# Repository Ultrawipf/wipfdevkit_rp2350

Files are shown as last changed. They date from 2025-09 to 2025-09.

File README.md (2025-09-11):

## DM 14 Wipf

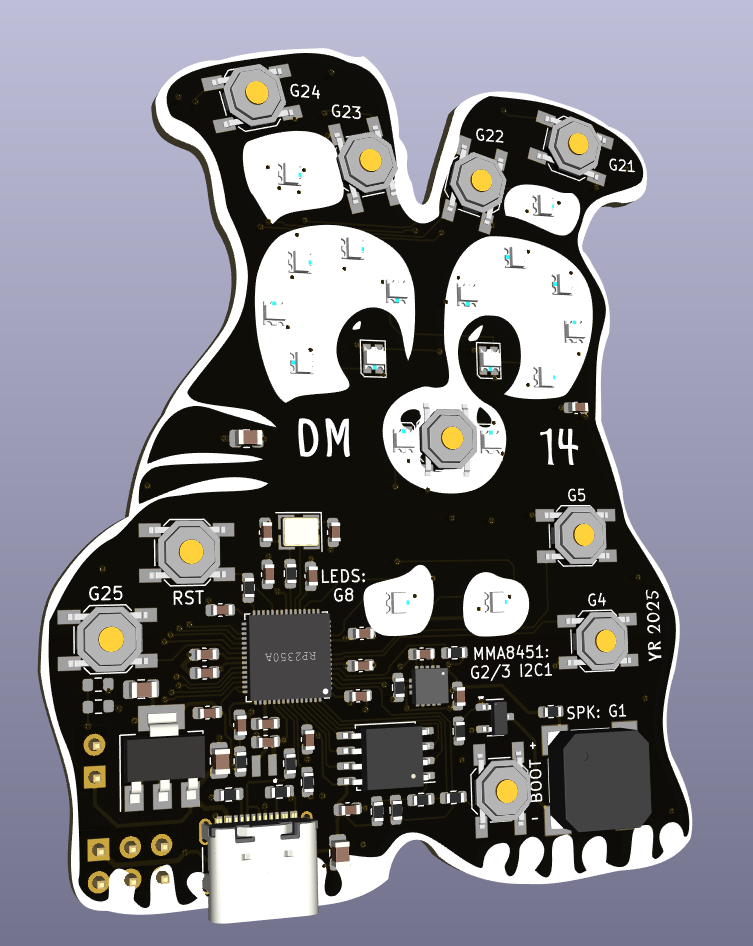
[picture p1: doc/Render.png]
Board


### Requirements:

* [Circuitpython](https://circuitpython.org/board/raspberry_pi_pico2/)
* Circuitpython [library bundle](https://circuitpython.org/libraries)

### Features
* RP2350 (Raspberry pi pico 2)
* 16MB Flash
* 520kB ram
* Dual core ARM + RiscV
* FS USB

#### Functions
* 18 WS2812 leds: GP8
* [MMA8451](https://www.lcsc.com/product-detail/C118083.html) Accelerometer : I2C GP 2/3
* [Buzzer](https://www.lcsc.com/product-detail/C18623826.html) (Beep,Boop,Snuff) : GP1
* 8 Buttons
* [Circuitpython](https://docs.circuitpython.org/en/latest/README.html)

#### Demoprogram
* HID Clonk keyboard mode
* Accelerometer demo
* Buzzer demo
* Disco lights
* Async python

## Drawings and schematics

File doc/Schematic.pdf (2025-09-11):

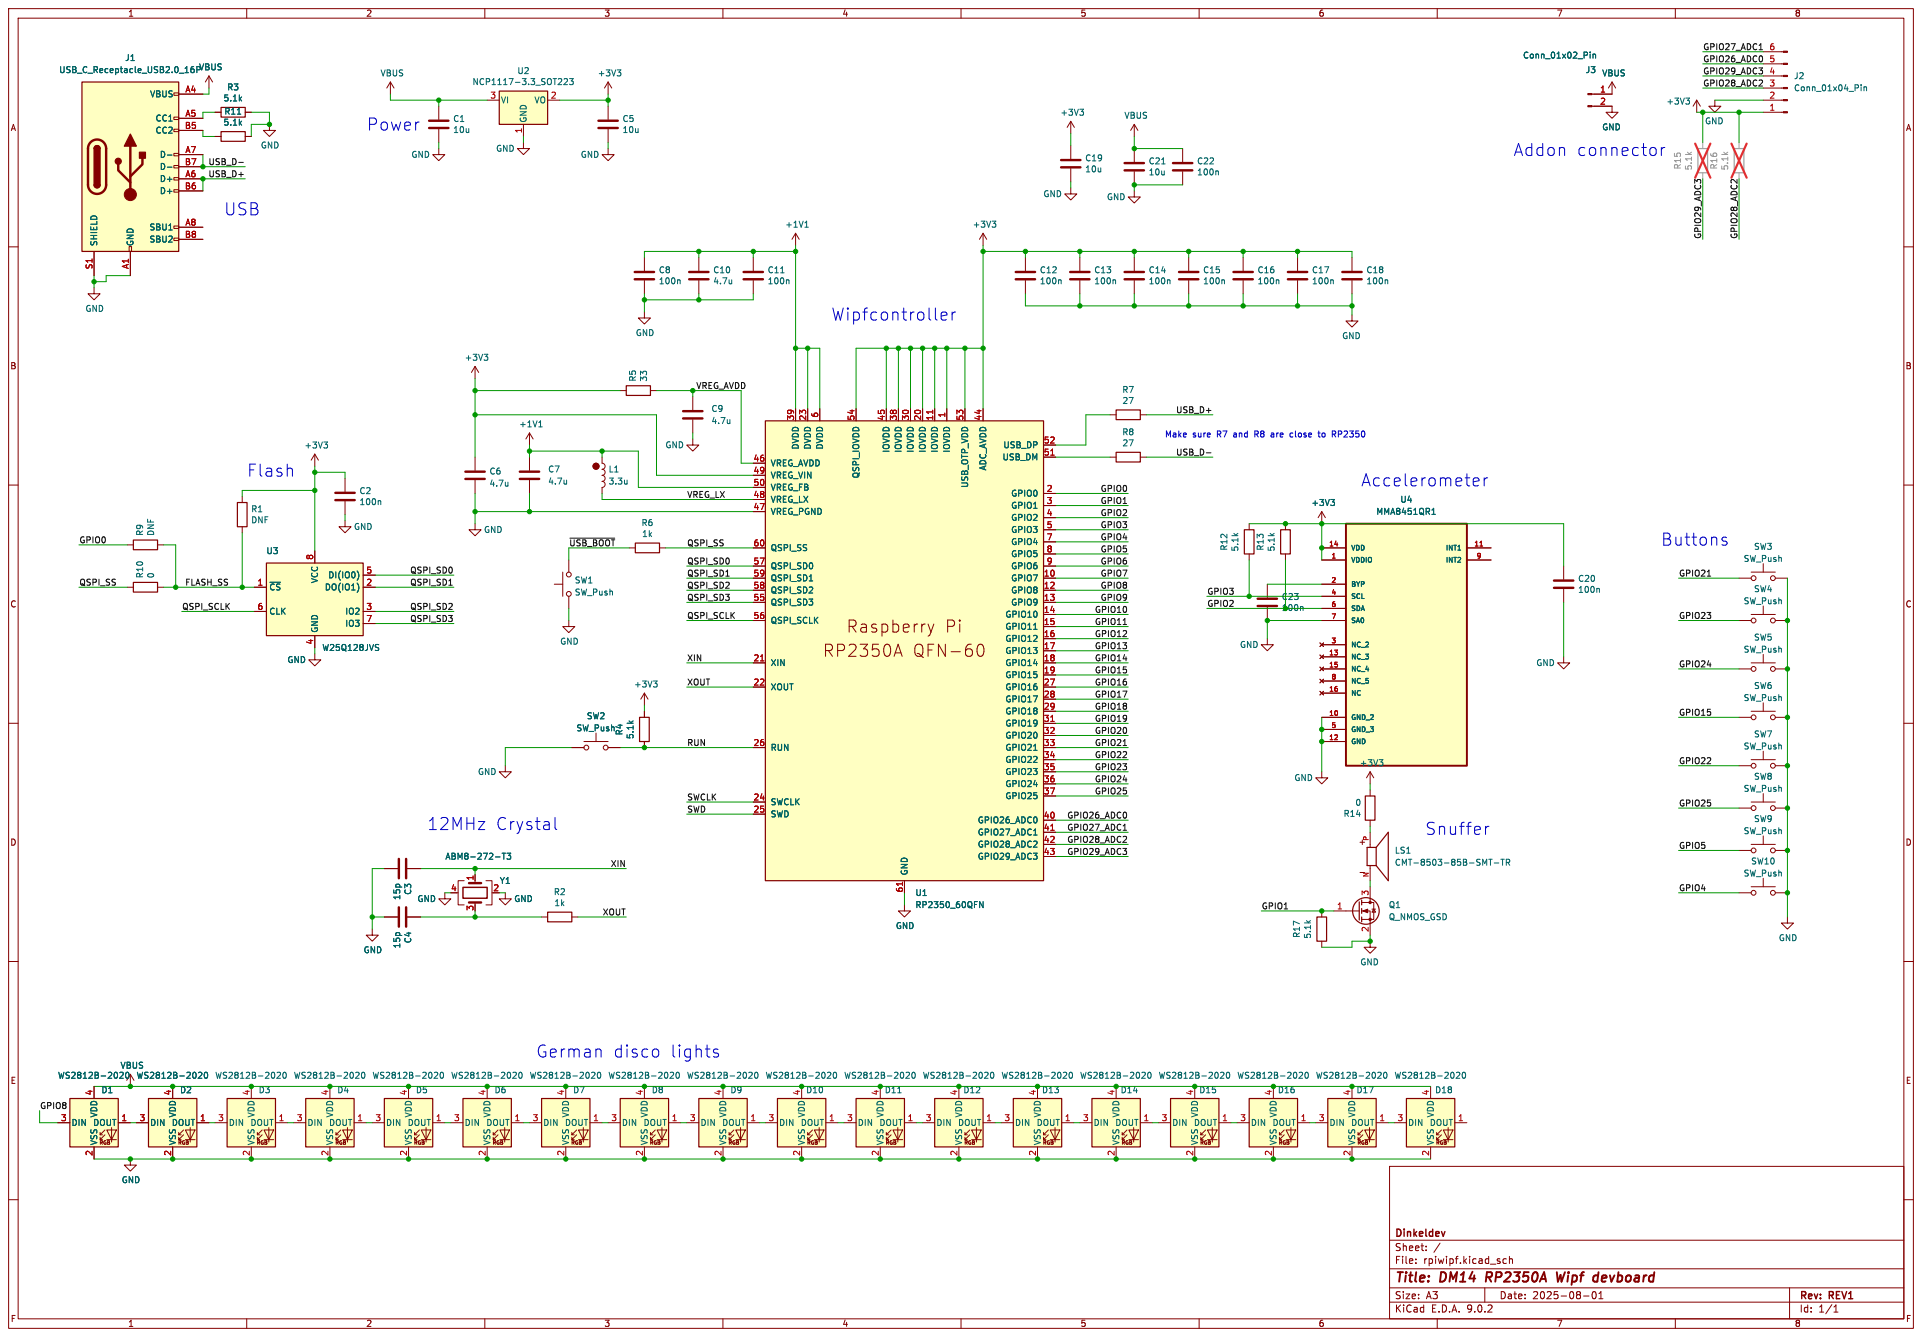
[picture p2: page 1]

Make sure R7 and R8 are close to RP2350 Wipfcontroller

6 QSPI_IOVDD 54 IOVDD 45 IOVDD 38 GND 61 IOVDD 30 IOVDD 20 IOVDD 11 IOVDD
27 Raspberry Pi

2 DOUT 1VBUS GND GND C4 15p GND C3 15p GND GND

File: rpiwipf.kicad_sch Sheet: / Dinkeldev

Id: 1/1 Title: DM14 RP2350A Wipf devboard

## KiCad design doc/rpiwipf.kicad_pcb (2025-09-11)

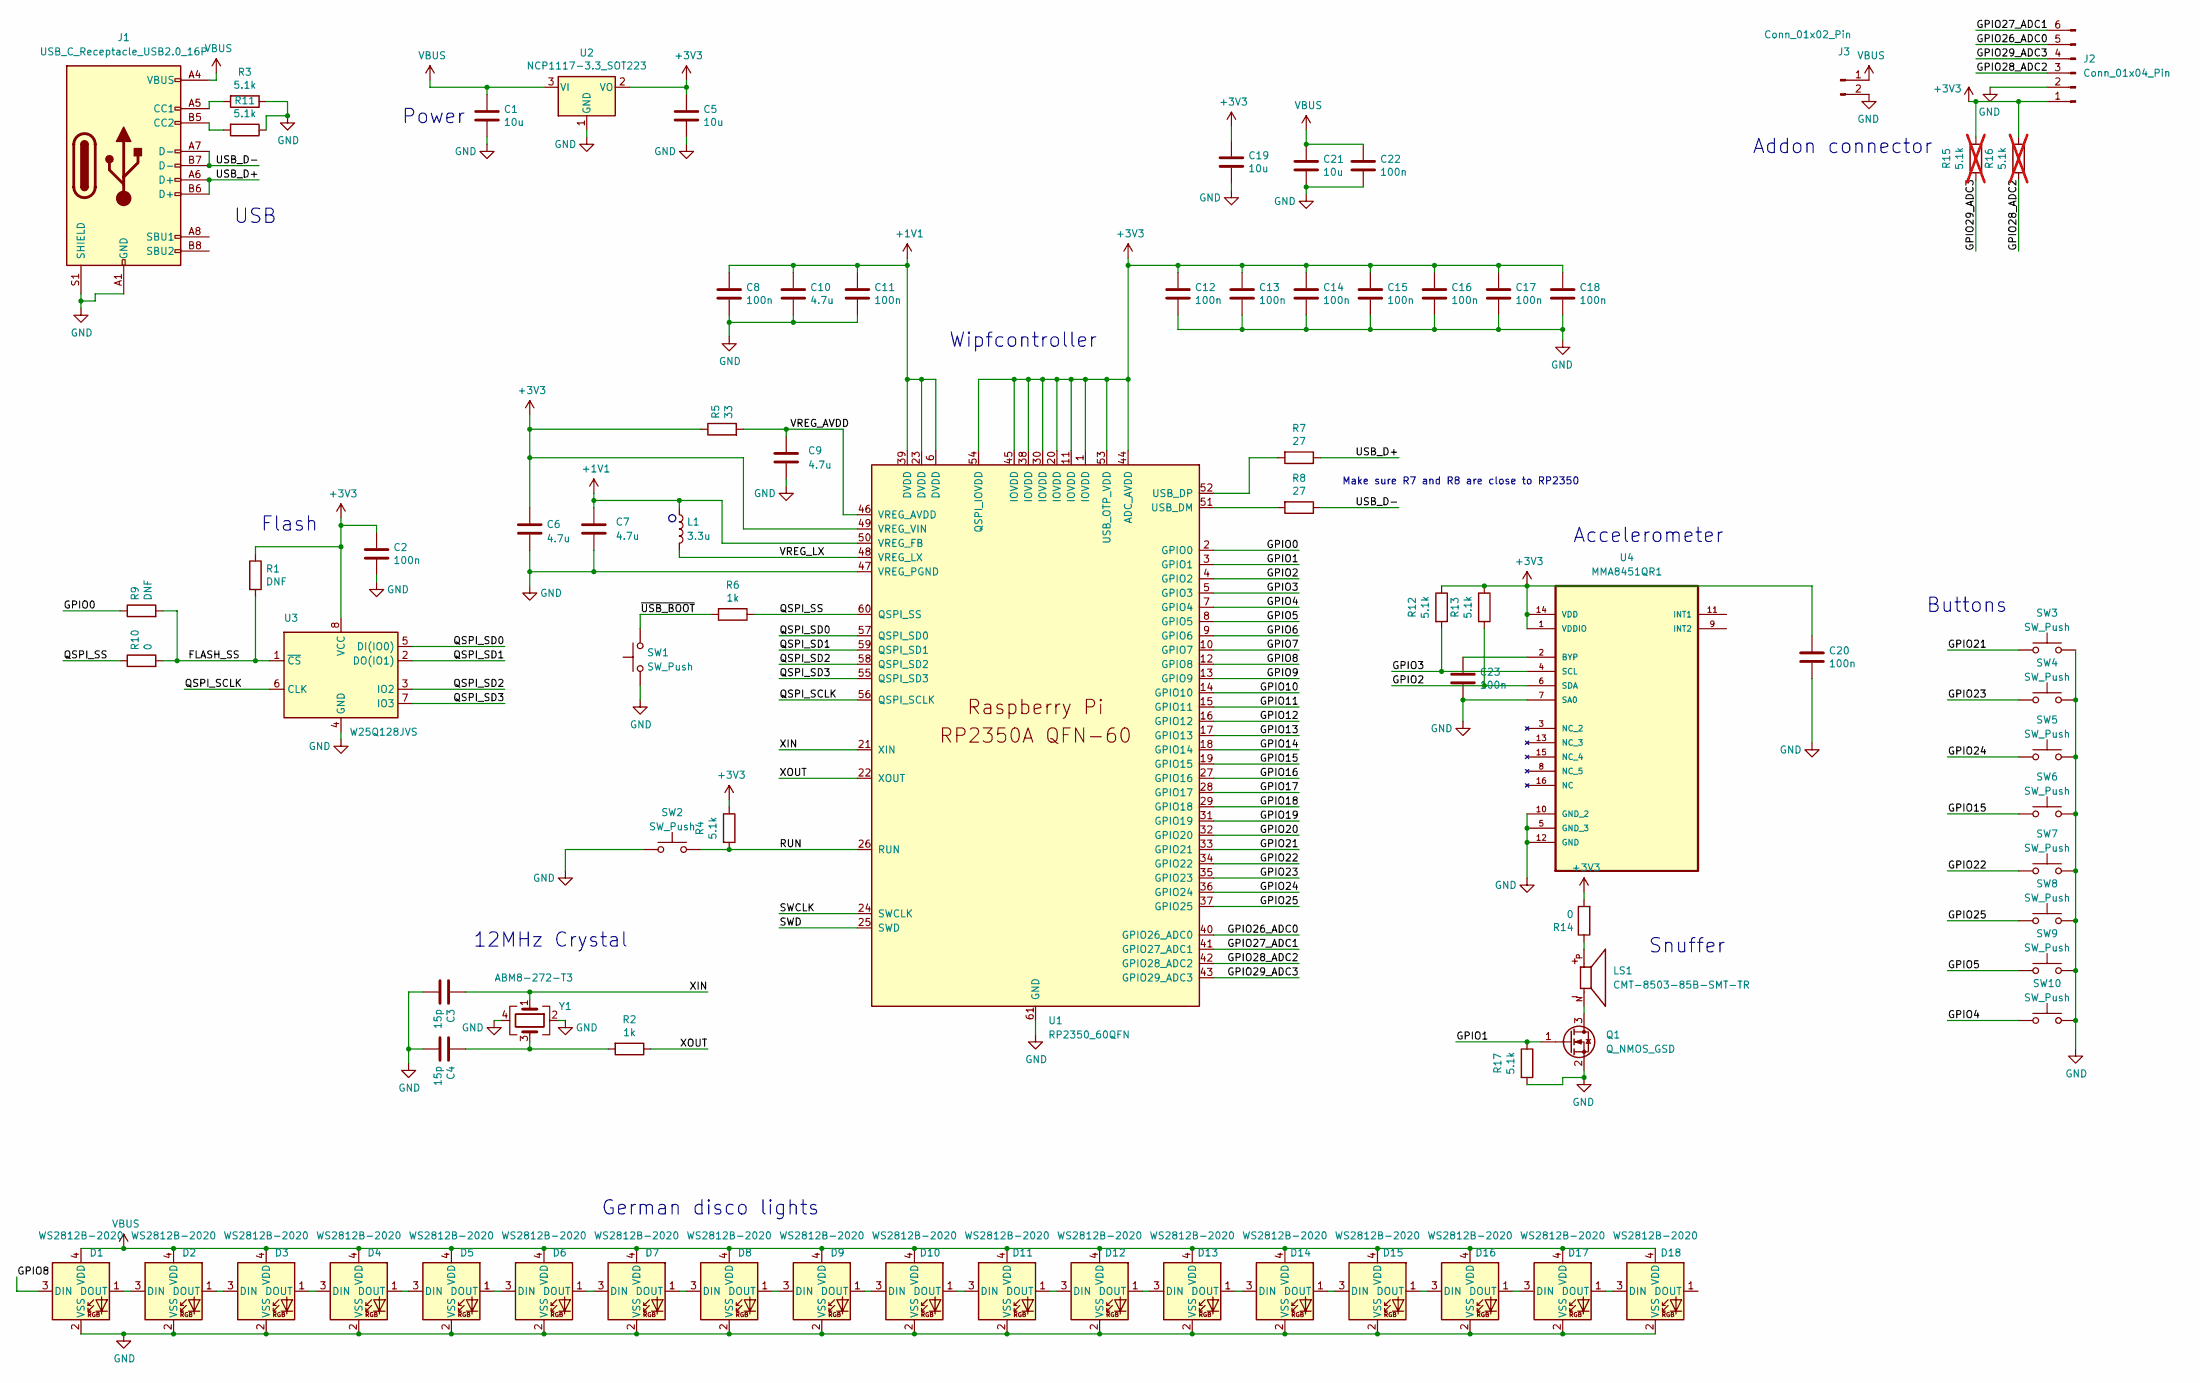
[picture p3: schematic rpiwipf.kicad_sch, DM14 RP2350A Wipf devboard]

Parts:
C1, C5, C19, C21: 10u; C_0805_2012Metric
C2, C8, C11, C12, C13, C14, C15, C16, C17, C18, C20, C22, C23: 100n; C_0603_1608Metric
C3, C4: 15p; C_0603_1608Metric
C6, C7, C9, C10: 4.7u; C_0603_1608Metric
D1, D2, D3, D4, D5, D6, D7, D8, D9, D10, D11, D12, D13, D14, D15, D16, D17, D18: WS2812B-2020; LED_WS2812B-2020_PLCC4_2.0x2.0mm
J1: USB_C_Receptacle_USB2.0_16P; USB_C_Receptacle_XKB_U262-16XN-4BVC11
J2: Conn_01x04_Pin; PinHeader_2x03_P2.54mm_Vertical
J3: Conn_01x02_Pin; PinHeader_1x02_P2.54mm_Vertical
L1: 3.3u; L_pol_2016
LS1: CMT-8503-85B-SMT-TR; XDCR_CMT-8503-85B-SMT-TR; PARTREV 1.0
Q1: Q_NMOS_GSD; SOT-23-3
R1, R9: DNF; R_0603_1608Metric
R2, R6: 1k; R_0603_1608Metric
R3, R4, R11, R12, R13, R17: 5.1k; R_0603_1608Metric
R5: 33; R_0603_1608Metric
R7, R8: 27; R_0603_1608Metric
R10, R14: 0; R_0603_1608Metric
R15, R16: 5.1k; R_0603_1608Metric; not fitted
SW1, SW2, SW3, SW4, SW5, SW6, SW7, SW8, SW9, SW10: SW_Push; SW_SPST_SKQG_WithoutStem
U1: RP2350_60QFN; RP2350-QFN-60-1EP_7x7_P0.4mm_EP3.4x3.4mm_ThermalVias
U2: NCP1117-3.3_SOT223; SOT-223-3_TabPin2
U3: W25Q128JVS; SOIC-8_5.23x5.23mm_P1.27mm
U4: MMA8451QR1; QFN50P300X300X100-16N; MPN MMA8451QR1
Y1: ABM8-272-T3; Crystal_SMD_3225-4Pin_3.2x2.5mm

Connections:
+1V1: C7.1, C8.1, C10.1, C11.1, L1.1, U1.6 (DVDD), U1.23 (DVDD), U1.39 (DVDD), U1.50 (VREG_FB)
+3V3: C2.1, C5.1, C6.1, C12.1, C13.1, C14.1, C15.1, C16.1, C17.1, C18.1, C19.1, C20.1, J2.1, R1.1, R4.1, R5.1, R12.1, R13.1, R14.2, R15.1, R16.1, U1.1 (IOVDD), U1.11 (IOVDD), U1.20 (IOVDD), U1.30 (IOVDD), U1.38 (IOVDD), U1.44 (ADC_AVDD), U1.45 (IOVDD), U1.49 (VREG_VIN), U1.53 (USB_OTP_VDD), U1.54 (QSPI_IOVDD), U2.2 (VO), U3.8 (VCC), U4.1 (VDDIO), U4.14 (VDD)
/FLASH_SS: R1.2, R9.2, R10.2, U3.1 (~CS)
/GPIO0: R9.1, U1.2 (GPIO0)
/GPIO1: Q1.1 (G), R17.1, U1.3 (GPIO1)
/GPIO2: R13.2, U1.4 (GPIO2), U4.6 (SDA)
/GPIO3: R12.2, U1.5 (GPIO3), U4.4 (SCL)
/GPIO4: SW10.1, U1.7 (GPIO4)
/GPIO5: SW9.1, U1.8 (GPIO5)
/GPIO6: U1.9 (GPIO6)
/GPIO7: U1.10 (GPIO7)
/GPIO8: D1.3 (DIN), U1.12 (GPIO8)
/GPIO9: U1.13 (GPIO9)
/GPIO10: U1.14 (GPIO10)
/GPIO11: U1.15 (GPIO11)
/GPIO12: U1.16 (GPIO12)
/GPIO13: U1.17 (GPIO13)
/GPIO14: U1.18 (GPIO14)
/GPIO15: SW6.1, U1.19 (GPIO15)
/GPIO16: U1.27 (GPIO16)
/GPIO17: U1.28 (GPIO17)
/GPIO18: U1.29 (GPIO18)
/GPIO19: U1.31 (GPIO19)
/GPIO20: U1.32 (GPIO20)
/GPIO21: SW3.1, U1.33 (GPIO21)
/GPIO22: SW7.1, U1.34 (GPIO22)
/GPIO23: SW4.1, U1.35 (GPIO23)
/GPIO24: SW5.1, U1.36 (GPIO24)
/GPIO25: SW8.1, U1.37 (GPIO25)
/GPIO26_ADC0: J2.5, U1.40 (GPIO26_ADC0)
/GPIO27_ADC1: J2.6, U1.41 (GPIO27_ADC1)
/GPIO28_ADC2: J2.3, R16.2, U1.42 (GPIO28_ADC2)
/GPIO29_ADC3: J2.4, R15.2, U1.43 (GPIO29_ADC3)
/QSPI_SCLK: U1.56 (QSPI_SCLK), U3.6 (CLK)
/QSPI_SD0: U1.57 (QSPI_SD0), U3.5 (DI(IO0))
/QSPI_SD1: U1.59 (QSPI_SD1), U3.2 (DO(IO1))
/QSPI_SD2: U1.58 (QSPI_SD2), U3.3 (IO2)
/QSPI_SD3: U1.55 (QSPI_SD3), U3.7 (IO3)
/QSPI_SS: R6.1, R10.1, U1.60 (QSPI_SS)
/RUN: R4.2, SW2.2, U1.26 (RUN)
/SWCLK: U1.24 (SWCLK)
/SWD: U1.25 (SWD)
/USB_D+: J1.A6 (D+), J1.B6 (D+), R7.1
/USB_D-: J1.A7 (D-), J1.B7 (D-), R8.1
/VREG_AVDD: C9.1, R5.2, U1.46 (VREG_AVDD)
/VREG_LX: L1.2, U1.48 (VREG_LX)
/XIN: C3.1, U1.21 (XIN), Y1.1
/XOUT: R2.1, U1.22 (XOUT)
/~USB_BOOT: R6.2, SW1.2
GND: C1.2, C2.2, C3.2, C4.2, C5.2, C6.2, C7.2, C8.2, C9.2, C10.2, C11.2, C12.2, C13.2, C14.2, C15.2, C16.2, C17.2, C18.2, C19.2, C20.2, C21.2, C22.2, C23.2, D1.2 (VSS), D2.2 (VSS), D3.2 (VSS), D4.2 (VSS), D5.2 (VSS), D6.2 (VSS), D7.2 (VSS), D8.2 (VSS), D9.2 (VSS), D10.2 (VSS), D11.2 (VSS), D12.2 (VSS), D13.2 (VSS), D14.2 (VSS), D15.2 (VSS), D16.2 (VSS), D17.2 (VSS), D18.2 (VSS), J1.A1 (GND), J1.A12 (GND), J1.B1 (GND), J1.B12 (GND), J1.S1 (SHIELD), J2.2, J3.2, Q1.2 (S), R3.1, R11.1, R17.2, SW1.1, SW2.1, SW3.2, SW4.2, SW5.2, SW6.2, SW7.2, SW8.2, SW9.2, SW10.2, U1.47 (VREG_PGND), U1.61 (GND), U2.1 (GND), U3.4 (GND), U4.5 (GND_3), U4.7 (SA0), U4.10 (GND_2), U4.12 (GND), Y1.2, Y1.4
unnamed: C4.1, R2.2, Y1.3
unnamed: D1.1 (DOUT), D2.3 (DIN)
unnamed: D2.1 (DOUT), D3.3 (DIN)
unnamed: D3.1 (DOUT), D4.3 (DIN)
unnamed: D4.1 (DOUT), D5.3 (DIN)
unnamed: D5.1 (DOUT), D6.3 (DIN)
unnamed: D6.1 (DOUT), D7.3 (DIN)
unnamed: D7.1 (DOUT), D8.3 (DIN)
unnamed: D8.1 (DOUT), D9.3 (DIN)
unnamed: D9.1 (DOUT), D10.3 (DIN)
unnamed: D10.1 (DOUT), D11.3 (DIN)
unnamed: D11.1 (DOUT), D12.3 (DIN)
unnamed: D12.1 (DOUT), D13.3 (DIN)
unnamed: D13.1 (DOUT), D14.3 (DIN)
unnamed: D14.1 (DOUT), D15.3 (DIN)
unnamed: D15.1 (DOUT), D16.3 (DIN)
unnamed: D16.1 (DOUT), D17.3 (DIN)
unnamed: D17.1 (DOUT), D18.3 (DIN)
unnamed: J1.A5 (CC1), R3.2
unnamed: J1.B5 (CC2), R11.2
unnamed: LS1.P, R14.1
unnamed: LS1.N, Q1.3 (D)
unnamed: R8.2, U1.51 (USB_DM)
unnamed: R7.2, U1.52 (USB_DP)
unnamed: C23.1, U4.2 (BYP)
VBUS: C1.1, C21.1, C22.1, D1.4 (VDD), D2.4 (VDD), D3.4 (VDD), D4.4 (VDD), D5.4 (VDD), D6.4 (VDD), D7.4 (VDD), D8.4 (VDD), D9.4 (VDD), D10.4 (VDD), D11.4 (VDD), D12.4 (VDD), D13.4 (VDD), D14.4 (VDD), D15.4 (VDD), D16.4 (VDD), D17.4 (VDD), D18.4 (VDD), J1.A4 (VBUS), J1.A9 (VBUS), J1.B4 (VBUS), J1.B9 (VBUS), J3.1, U2.3 (VI)

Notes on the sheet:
Snuffer
Flash
Wipfcontroller
Make sure R7 and R8 are close to RP2350
USB
Addon connector
Buttons
German disco lights
12MHz Crystal
Power
Accelerometer

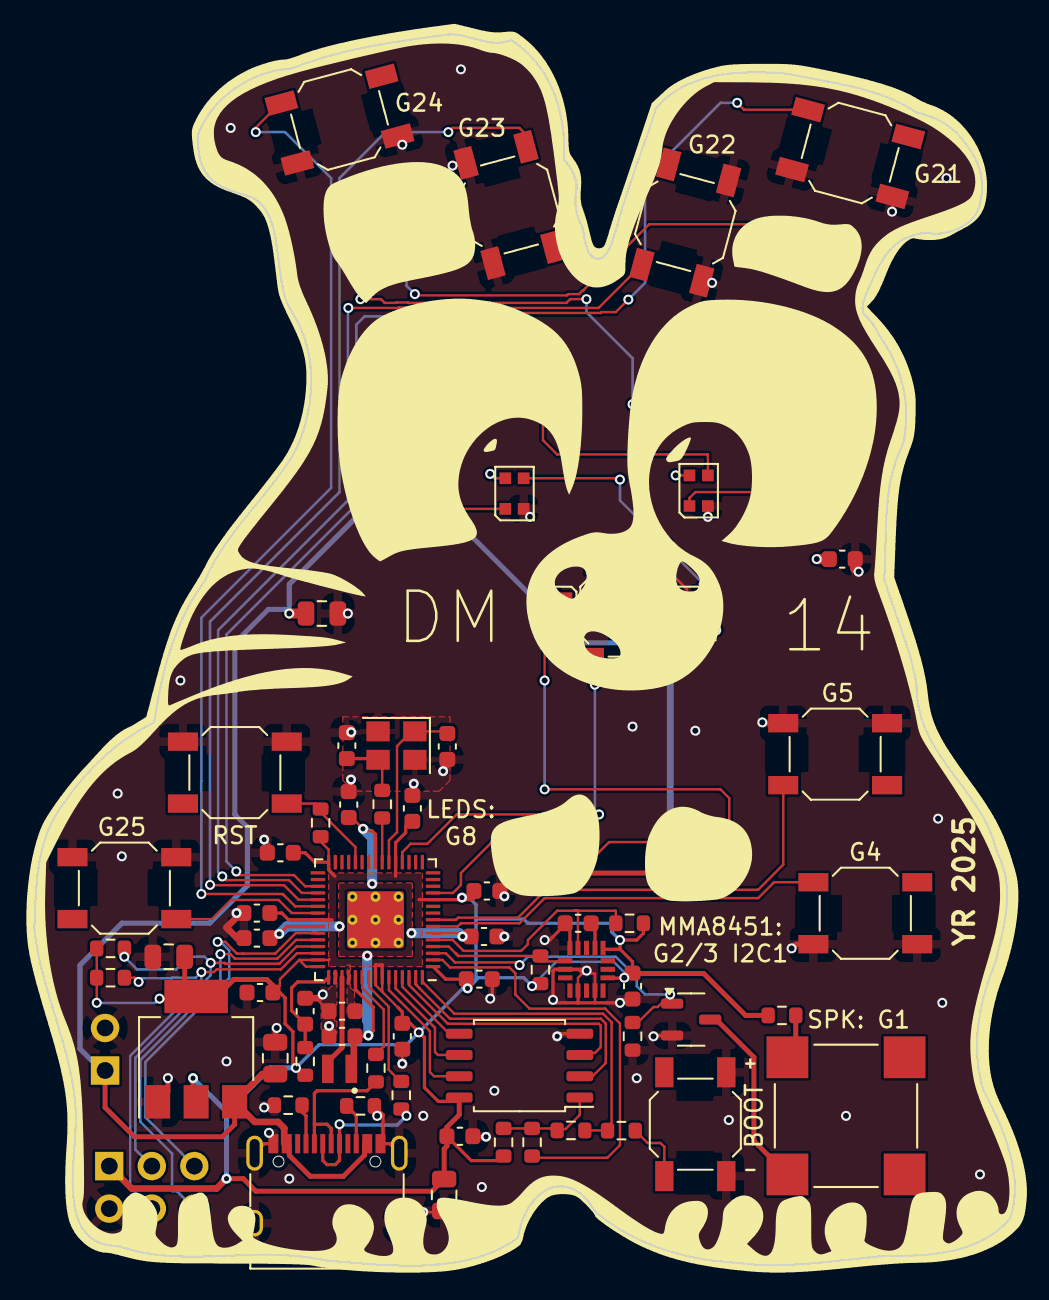
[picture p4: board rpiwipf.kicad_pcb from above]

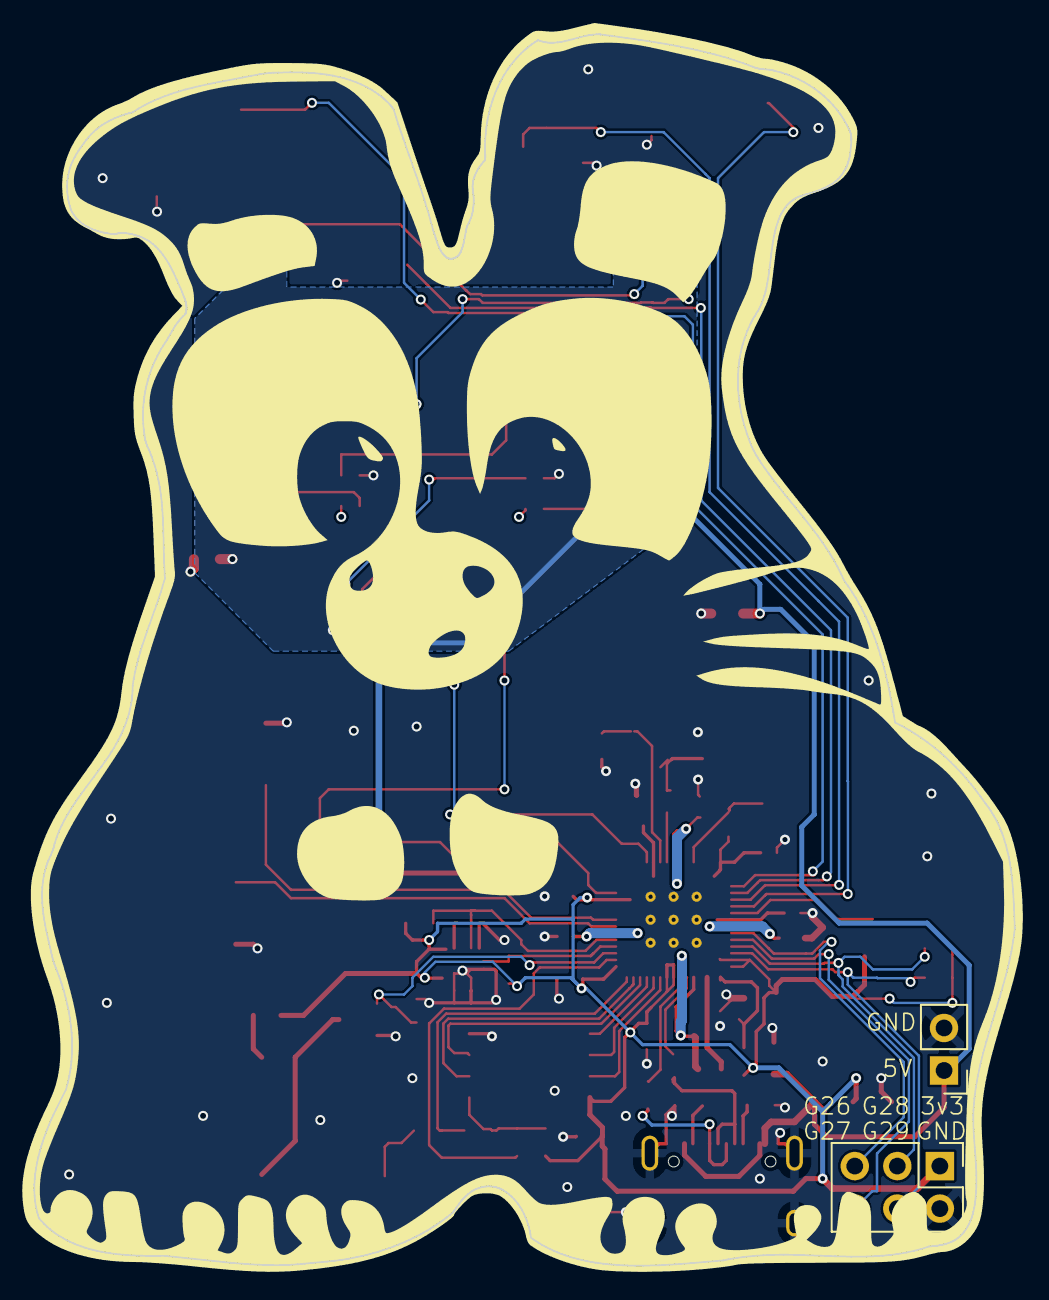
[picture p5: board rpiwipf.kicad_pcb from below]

Board: 2 copper layers, 58.6 x 73.5 mm, 79 parts (2 on the bottom side), 61 nets.

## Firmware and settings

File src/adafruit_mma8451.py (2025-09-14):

# SPDX-FileCopyrightText: 2017 Tony DiCola for Adafruit Industries
#
# SPDX-License-Identifier: MIT

# INFO: Disables probe param. Must replace with original


"""
`adafruit_mma8451`
====================================================

CircuitPython module for the MMA8451 3 axis accelerometer.  See
examples/simpletest.py for a demo of the usage.

* Author(s): Tony DiCola

Implementation Notes
--------------------

**Hardware:**

* Adafruit `Triple-Axis Accelerometer - ±2/4/8g @ 14-bit - MMA8451
  <https://www.adafruit.com/product/2019>`_


**Software and Dependencies:**

* Adafruit CircuitPython firmware for the supported boards:
  https://circuitpython.org/downloads
* Adafruit's Bus Device library:
  https://github.com/adafruit/Adafruit_CircuitPython_BusDevice

"""

import struct

#from adafruit_bus_device import i2c_device
from micropython import const

try:
    from typing import Optional, Tuple

    from busio import I2C
except ImportError:
    pass

import time


__version__ = "1.3.25"
__repo__ = "https://github.com/adafruit/Adafruit_CircuitPython_MMA8451.git"


# Internal constants:
_MMA8451_DEFAULT_ADDRESS = const(0x1D)
_MMA8451_REG_OUT_X_MSB = const(0x01)
_MMA8451_REG_SYSMOD = const(0x0B)
_MMA8451_REG_WHOAMI = const(0x0D)
_MMA8451_REG_XYZ_DATA_CFG = const(0x0E)
_MMA8451_REG_PL_STATUS = const(0x10)
_MMA8451_REG_PL_CFG = const(0x11)
_MMA8451_REG_CTRL_REG1 = const(0x2A)
_MMA8451_REG_CTRL_REG2 = const(0x2B)
_MMA8451_REG_CTRL_REG4 = const(0x2D)
_MMA8451_REG_CTRL_REG5 = const(0x2E)
_MMA8451_DATARATE_MASK = const(0b111)
_SENSORS_GRAVITY_EARTH = 9.80665

# External user-facing constants:
PL_PUF = 0  # Portrait, up, front
PL_PUB = 1  # Portrait, up, back
PL_PDF = 2  # Portrait, down, front
PL_PDB = 3  # Portrait, down, back
PL_LRF = 4  # Landscape, right, front
PL_LRB = 5  # Landscape, right, back
PL_LLF = 6  # Landscape, left, front
PL_LLB = 7  # Landscape, left, back
RANGE_8G = 0b10  # +/- 8g
RANGE_4G = 0b01  # +/- 4g (default value)
RANGE_2G = 0b00  # +/- 2g
DATARATE_800HZ = 0b000  #  800Hz
DATARATE_400HZ = 0b001  #  400Hz
DATARATE_200HZ = 0b010  #  200Hz
DATARATE_100HZ = 0b011  #  100Hz
DATARATE_50HZ = 0b100  #   50Hz
DATARATE_12_5HZ = 0b101  # 12.5Hz
DATARATE_6_25HZ = 0b110  # 6.25Hz
DATARATE_1_56HZ = 0b111  # 1.56Hz


class MMA8451:
    """MMA8451 accelerometer.  Create an instance by specifying:

    :param ~busio.I2C i2c: The I2C bus the device is connected to.
    :param int address: The I2C device address. Defaults to :const:`0x1D`


    **Quickstart: Importing and using the device**

        Here is an example of using the :class:`MMA8451` class.
        First you will need to import the libraries to use the sensor

        .. code-block:: python

            import board
            import adafruit_mma8451

        Once this is done you can define your `board.I2C` object and define your sensor object

        .. code-block:: python

            i2c = board.I2C()  # uses board.SCL and board.SDA
            sensor = adafruit_mma8451.MMA8451(i2c)

        Now you have access to the :attr:`acceleration` and :attr:`orientation` attributes

        .. code-block:: python

            acc_x, acc_y, acc_z = sensor.acceleration
            orientation = sensor.orientation

    """

    # Class-level buffer to reduce allocations and fragmentation.
    # Note this is NOT thread-safe or re-entrant by design!
    _BUFFER = bytearray(6)

    def __init__(self, i2c: I2C, *, address: int = _MMA8451_DEFAULT_ADDRESS) -> None:
        #self._device = i2c_device.I2CDevice(i2c, address,False)
        # Verify device ID.
        self.i2c = i2c
        self.addr = address
        # self.i2c.try_lock()
        # print(self.i2c.scan())
        # self.i2c.unlock()
        if self._read_u8(_MMA8451_REG_WHOAMI) != 0x1A:
            raise RuntimeError("Failed to find MMA8451, check wiring!")
        # Reset and wait for chip to be ready.
        self._write_u8(_MMA8451_REG_CTRL_REG2, 0x40)
        time.sleep(0.001)
        while self._read_u8(_MMA8451_REG_CTRL_REG2) & 0x40 > 0:
            time.sleep(0.001)
            pass
        # Enable 4G range.
        self._write_u8(_MMA8451_REG_XYZ_DATA_CFG, RANGE_4G)
        # High resolution mode.
        self._write_u8(_MMA8451_REG_CTRL_REG2, 0x02)
        # DRDY on INT1
        self._write_u8(_MMA8451_REG_CTRL_REG4, 0x01)
        self._write_u8(_MMA8451_REG_CTRL_REG5, 0x01)
        # Turn on orientation config
        self._write_u8(_MMA8451_REG_PL_CFG, 0x40)
        # Activate at max rate, low noise mode
        self._write_u8(_MMA8451_REG_CTRL_REG1, 0x01 | 0x04)

    def _read_into(self, address: int, buf: bytearray, count: Optional[int] = None) -> bytearray:
        # Read bytes from the specified address into the provided buffer.
        # If count is not specified (the default) the entire buffer is filled,
        # otherwise only count bytes are copied in.
        # It's silly that pylint complains about an explicit check that buf
        # has at least 1 value.  I don't trust the implicit true/false
        # recommendation as it was not designed for bytearrays which may not
        # follow that semantic.  Ignore pylint's superfulous complaint.
        assert len(buf) > 0
        if count is None:
            count = len(buf)
        #with self._device as i2c:
        while not self.i2c.try_lock():
            pass
        #self.i2c.write_then_readinto(bytes([address & 0xFF]), buf, in_end=count)
        self.i2c.writeto_then_readfrom(self.addr,bytes([address & 0xFF]), buf,out_end=1, in_end=count)
        
        self.i2c.unlock()
    def _read_u8(self, address: int) -> int:
        # Read an 8-bit unsigned value from the specified 8-bit address.
        self._read_into(address, self._BUFFER, count=1)
        return self._BUFFER[0]

    def _write_u8(self, address: int, val: int) -> None:
        # Write an 8-bit unsigned value to the specified 8-bit address.ä
        while not self.i2c.try_lock():
            pass
        #with self._device as i2c:
        self._BUFFER[0] = address & 0xFF
        self._BUFFER[1] = val & 0xFF
        #self.i2c.write(self._BUFFER, end=2)
        self.i2c.writeto(self.addr,self._BUFFER, end=2)
        
        self.i2c.unlock()

    @property
    def range(self) -> int:
        """Get and set the range of the sensor.  Must be a value of:

        * ``RANGE_8G``: +/- 8g
        * ``RANGE_4G``: +/- 4g (the default)
        * ``RANGE_2G``: +/- 2g

        """
        return self._read_u8(_MMA8451_REG_XYZ_DATA_CFG) & 0x03

    @range.setter
    def range(self, val: int) -> None:
        assert 0 <= val <= 2
        reg1 = self._read_u8(_MMA8451_REG_CTRL_REG1)
        self._write_u8(_MMA8451_REG_CTRL_REG1, 0x00)  # deactivate
        self._write_u8(_MMA8451_REG_XYZ_DATA_CFG, val)
        self._write_u8(_MMA8451_REG_CTRL_REG1, reg1 | 0x01)  # activate

    @property
    def data_rate(self) -> int:
        """Get and set the data rate of the sensor.  Must be a value of:
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

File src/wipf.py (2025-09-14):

import neopixel
import board
import pwmio
import adafruit_mma8451
from adafruit_led_animation.helper import PixelSubset

from digitalio import DigitalInOut,Direction, Pull
from busio import I2C

import audiocore
import audiopwmio
import asyncio
import time
import microcontroller

# LEDS
NUMLEDS = 18
PINLEDS = board.GP8
LEDS = neopixel.NeoPixel(PINLEDS, NUMLEDS)

# Led pin ids. use with LED[id]
LEDS_LEFTEYE = PixelSubset(LEDS,4,10)
LEDS_RIGHTEYE = PixelSubset(LEDS,10,16)
LEDS_TEETH = PixelSubset(LEDS,0,2)
LEDS_EARS = PixelSubset(LEDS,16,18)
LEDS_NOSE = PixelSubset(LEDS,2,4)

# Turn all off
LEDS.fill((0,0,0))
LEDS.show()

PINBUZZER = board.GP1
BUZZER_PWM = None #pwmio.PWMOut(PINBUZZER, variable_frequency=True)
BUZZER_AUD = None


I2C_EXT = I2C(scl=microcontroller.pin.GPIO29,sda=board.GP28,frequency=400000)
I2C_INT = I2C(scl=board.GP3,sda=board.GP2,frequency=400000)
I2C_EXT.try_lock()
devs = I2C_EXT.scan()
I2C_EXT.unlock()
print('I2C EXT',devs)
I2C_INT.try_lock()
devs = I2C_INT.scan()
I2C_INT.unlock()
print('I2C INT',devs)


for i in range(4):
    try:
        time.sleep(0.2) # Ensure accelerometer is found
        ACCELEROMETER = adafruit_mma8451.MMA8451(I2C_INT,address=0x1C)
        ACCELEROMETER.data_rate = adafruit_mma8451.DATARATE_200HZ
        #ACCELEROMETER.range=adafruit_mma8451.RANGE_8G
        print("Found accelerometer")
        break
    except Exception as e:
        # while not I2C_INT.try_lock():
        #     pass
        # I2C_INT.writeto(0x1C,bytes([0x2B,0x40]))
        # I2C_INT.unlock()
        ACCELEROMETER = None
        print("Accelerometer error",e)
        raise e
        time.sleep(1)
        
        



BUTTONPINS = [board.GP15,board.GP25,board.GP24,board.GP23,board.GP22,board.GP21,board.GP5,board.GP4]
BUTTONS = [DigitalInOut(pin) for pin in BUTTONPINS]

for btn in BUTTONS:
    btn.direction = Direction.INPUT
    btn.pull = Pull.UP

def get_button_states():
    """
    Returns True if a button is pressed
    """
    return [not btn.value for btn in BUTTONS]


def beep(freq = 0,duty = 65535//2):
    """
    Beeps using PWM
    """
    __switch_buzzer_to_pwm()
    if(freq):
        BUZZER_PWM.frequency = freq
        BUZZER_PWM.duty_cycle = duty  # On 50%
    else:
        BUZZER_PWM.duty_cycle = 0


def is_wav_playing():
    return BUZZER_AUD != None and BUZZER_AUD.playing

async def play_wav_async(file):
    global BUZZER_AUD
    if is_wav_playing():
        return

    __switch_buzzer_to_audio()
    
    wave = audiocore.WaveFile(file)

    BUZZER_AUD.play(wave)
    while BUZZER_AUD and BUZZER_AUD.playing:
        await asyncio.sleep(0.25)
    if BUZZER_AUD:
        BUZZER_AUD.deinit()
    BUZZER_AUD = None

def play_wav(file):
    global BUZZER_AUD
    __switch_buzzer_to_audio()
    wave = audiocore.WaveFile(file)
    print("Play",file)
    BUZZER_AUD.play(wave)
    while BUZZER_AUD.playing:
        pass
    print("stopped")
    BUZZER_AUD.deinit()
    BUZZER_AUD = None

    

def get_orientation():
    if ACCELEROMETER:
        return ACCELEROMETER.orientation
    else:
        return 128

def get_acceleration():
    if ACCELEROMETER:
        return ACCELEROMETER.acceleration
    else:
        return [0,0,0]
    


def __switch_buzzer_to_audio():
    global BUZZER_PWM
    global BUZZER_AUD
    if BUZZER_PWM:
        BUZZER_PWM.deinit()
        BUZZER_PWM = None
    if not BUZZER_AUD:
        BUZZER_AUD = audiopwmio.PWMAudioOut(PINBUZZER)

def __switch_buzzer_to_pwm():
    global BUZZER_PWM
    global BUZZER_AUD
    if BUZZER_AUD:
        BUZZER_AUD.deinit()
        BUZZER_AUD = None
    if not BUZZER_PWM:
        BUZZER_PWM = pwmio.PWMOut(PINBUZZER, variable_frequency=True)
